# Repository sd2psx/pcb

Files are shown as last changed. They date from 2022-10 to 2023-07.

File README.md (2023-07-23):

# sd2psx: PCB

<table>
<tr>
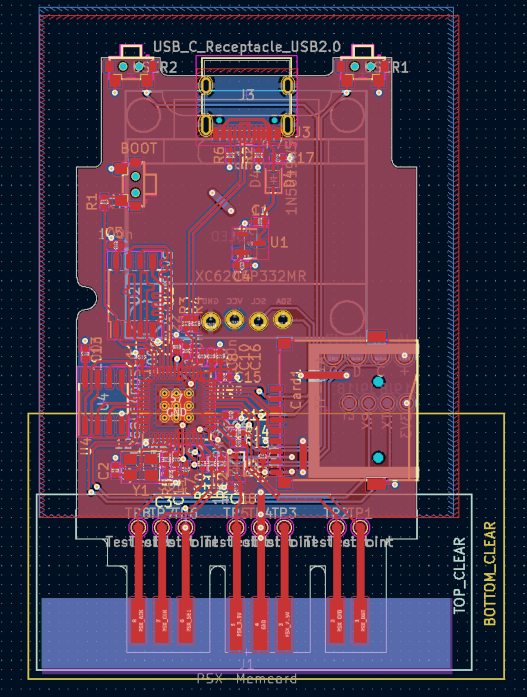
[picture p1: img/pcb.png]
    <td></td>
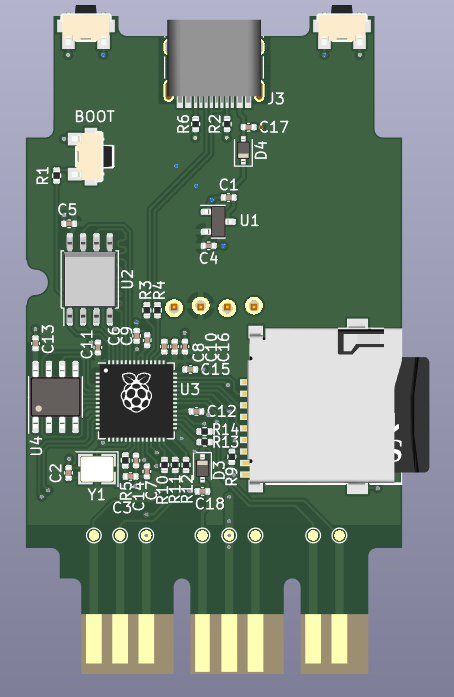
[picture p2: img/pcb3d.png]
    <td></td>
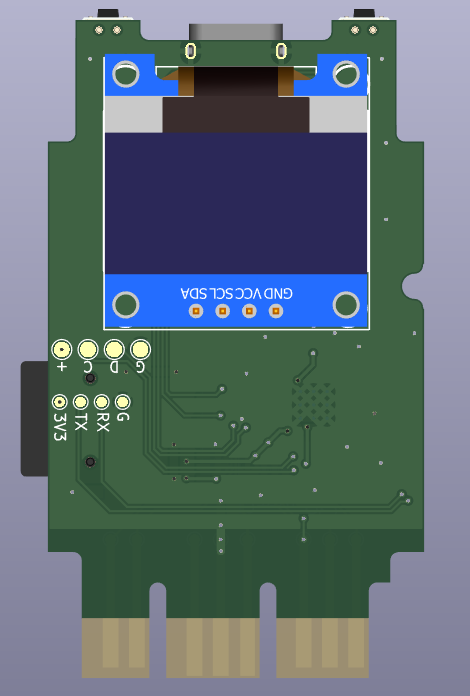
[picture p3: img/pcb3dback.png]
    <td></td>
</tr>
</table>

## Production notes

The PCB must be produced in 0.8mm thickness. Production files are provided under the "Releases" tab. These do not include the through-hole OLED module.

## PSRAM notes (LY68L6400SLIT)

As of June 2023, the LY68L6400SLIT is no longer available from JLCPCB. I've also seen multiple reports of people receiving a **fake chip** when purchasing one from aliexpress. The following chips are a drop-in replacement for the PSRAM:

* IPUS IPS6404LSQ
* ESP PSRAM64H
* AP 6404L-3SQR - Available from [Mouser](https://www.mouser.com/ProductDetail/AP-Memory/APS6404L-3SQR-SN?qs=IS%252B4QmGtzzqsn3S5xo%2FEEg%3D%3D)
* Lyontek LY68L6400S

I recommend switching to the AP 6404L-3SQR module; it can be assembled by JLCPCB by fist ordering it into your [personal parts library](https://jlcpcb.com/user-center/smtPrivateLibrary/?index=1).

## OLED module notes

The case requires a slim OLED module. The more common full-sized module will not fit into the case:

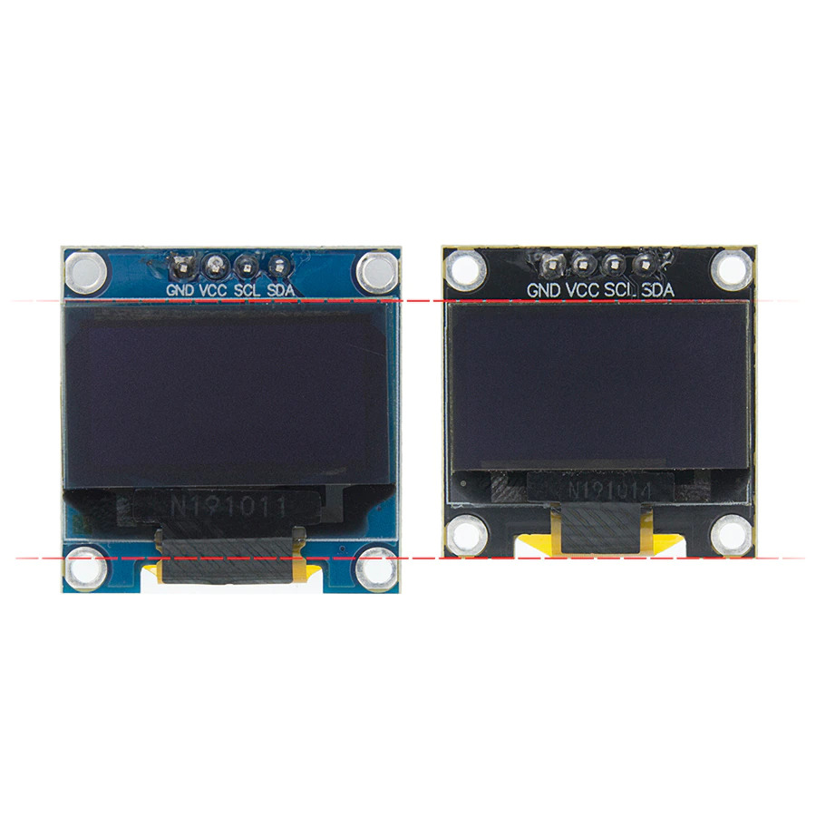
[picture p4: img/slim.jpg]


Examples of compatible modules:
- https://detail.tmall.com/item.htm?id=534583545403&skuId=3942158349315
- https://www.aliexpress.com/item/32638662748.html (make sure to select the smaller module marked as "New-White")

Spec sheet of a compatible module:

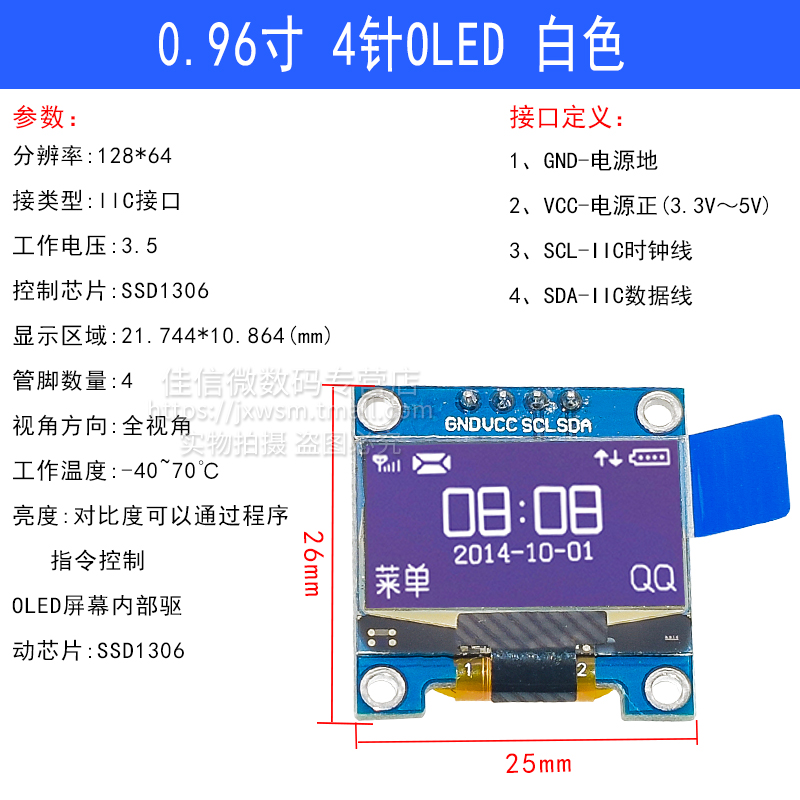
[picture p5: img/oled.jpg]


**Make sure that the pinout goes GND/VCC/SCL/SDA**. There are modules that swap GND/VCC around, these won't work.

## Assembly tips

When attaching the module to the PCB, remove protective OLED screen film (to prevent misalignment), then drop the module into the case so that the screen ends up flush against the case wall. Solder it on in that setup, then clip the pins:

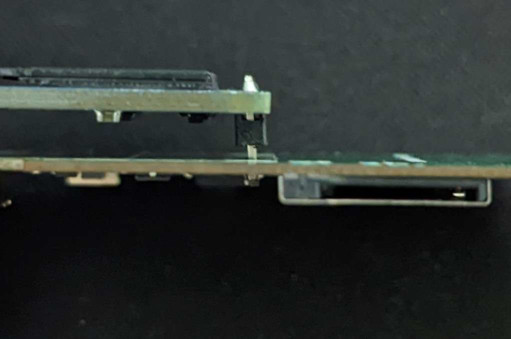
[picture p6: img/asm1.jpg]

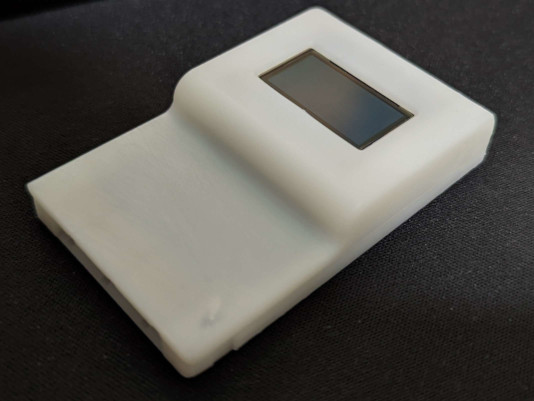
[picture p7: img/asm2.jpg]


There may be extra space between the pin header and the PCB, depending on your 3d print tolerances, but when fully assembled it should look nice and flush.

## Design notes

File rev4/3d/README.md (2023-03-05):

Files in this directory are **not** covered under the CERN-OHL-P license.

# HRO-TYPE-C-31-M-12.step

https://github.com/ai03-2725/Type-C.pretty/blob/master/HRO%20%20TYPE-C-31-M-12.step

# oled_128x64_25x66mm.stp

https://grabcad.com/library/0-96-inch-oled-lcd-module-4-pin-128x64-1

# RP2040_QFN_PACKAGE.STEP

https://grabcad.com/library/rp2040-1

# SOIC-8-208MIL.stp

https://grabcad.com/library/soic-8-208mils-1

# SWITCH_xiaobeibei.STEP

https://grabcad.com/library/tactile-switch-button-push-ts-018-2x4x3-5mm-1

# TF-01A.step

https://grabcad.com/library/tf-01a-1

# switch-3p.step

https://grabcad.com/library/tactile-switch-3p-4-5-x-4-5-x-9-mm-1

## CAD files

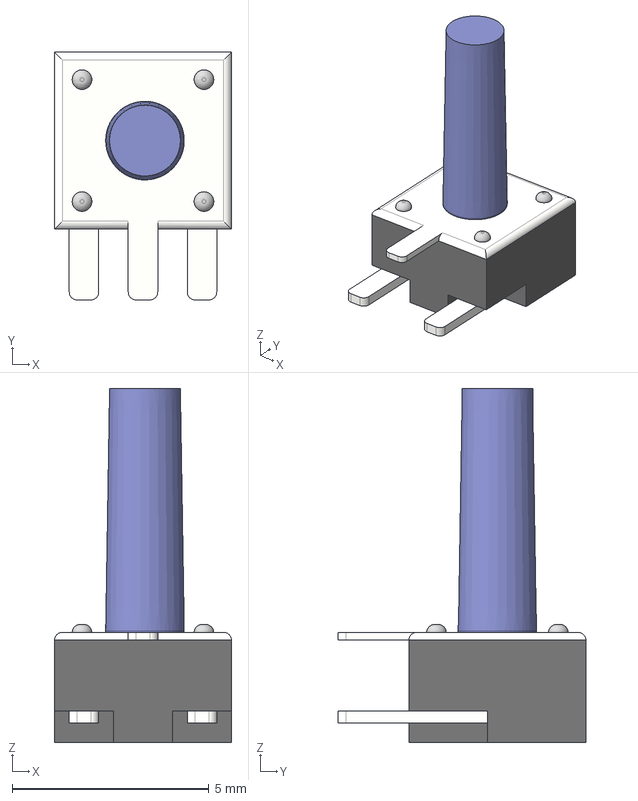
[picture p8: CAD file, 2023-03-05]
rev4/3d/switch-3p.step
4.50 x 6.30 x 9.00 mm

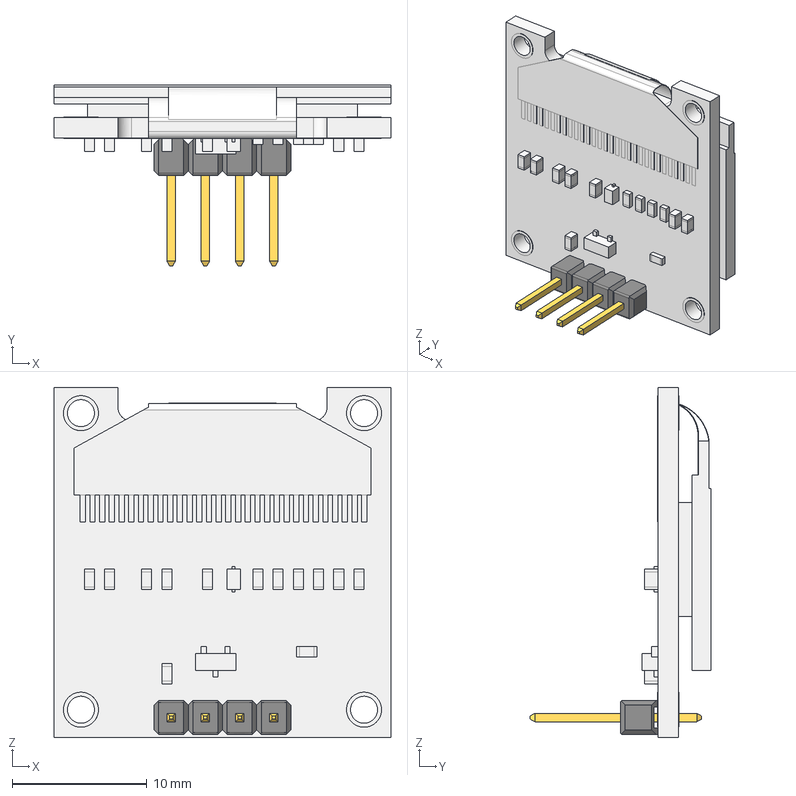
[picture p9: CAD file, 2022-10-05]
rev4/3d/oled_128x64_25x66mm.stp
25.0 x 13.4 x 26.0 mm
OSSD-128x64
brep_1
brep_2
brep_3
brep_4

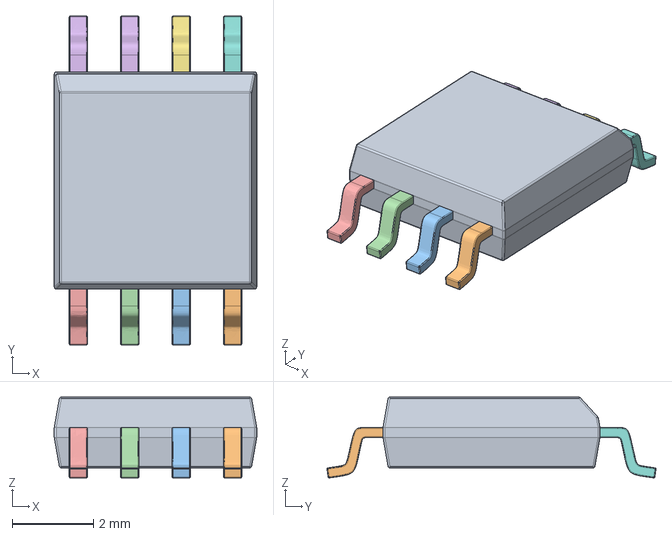
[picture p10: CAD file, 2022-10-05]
rev4/3d/SOIC-8-208MIL.stp
5.00 x 8.12 x 2.00 mm

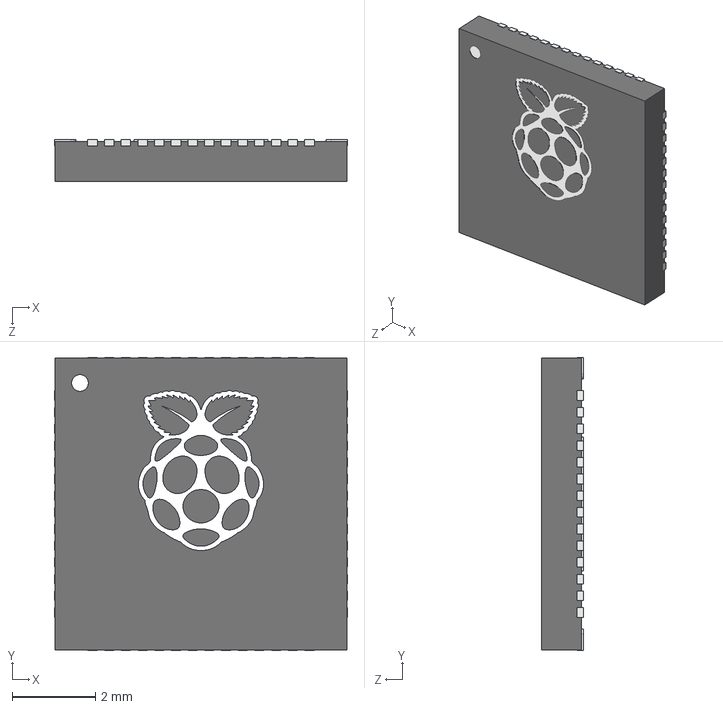
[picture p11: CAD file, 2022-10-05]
rev4/3d/RP2040_QFN_PACKAGE.STEP
7.02 x 7.02 x 1.00 mm

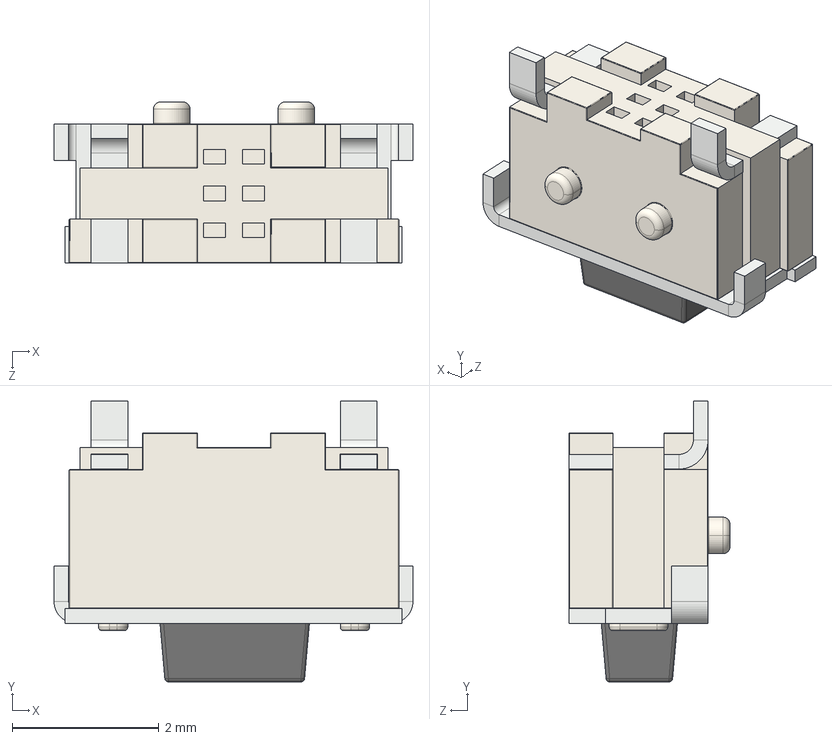
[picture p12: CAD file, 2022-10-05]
rev4/3d/SWITCH_xiaobeibei.STEP
4.90 x 3.83 x 2.20 mm
xiaobeibei_body
xiaobeibei_cap
xiaobeibei_plate
xiaobeibei_pin x 2

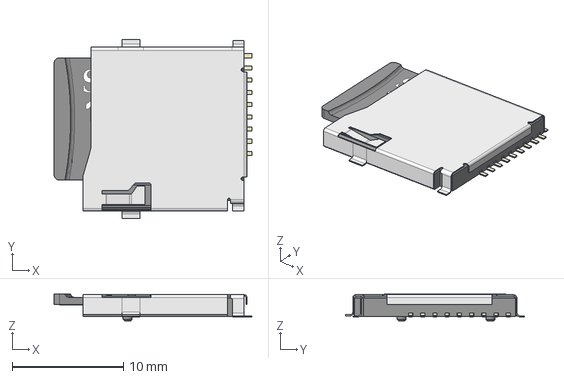
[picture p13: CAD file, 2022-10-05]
rev4/3d/TF-01A.step
17.8 x 16.1 x 2.40 mm

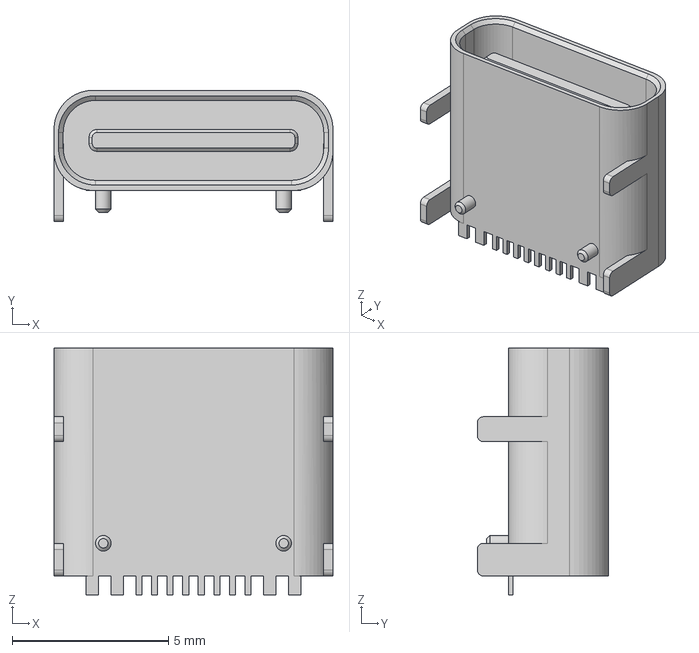
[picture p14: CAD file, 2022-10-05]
rev4/3d/HRO-TYPE-C-31-M-12.step
8.94 x 4.21 x 7.90 mm

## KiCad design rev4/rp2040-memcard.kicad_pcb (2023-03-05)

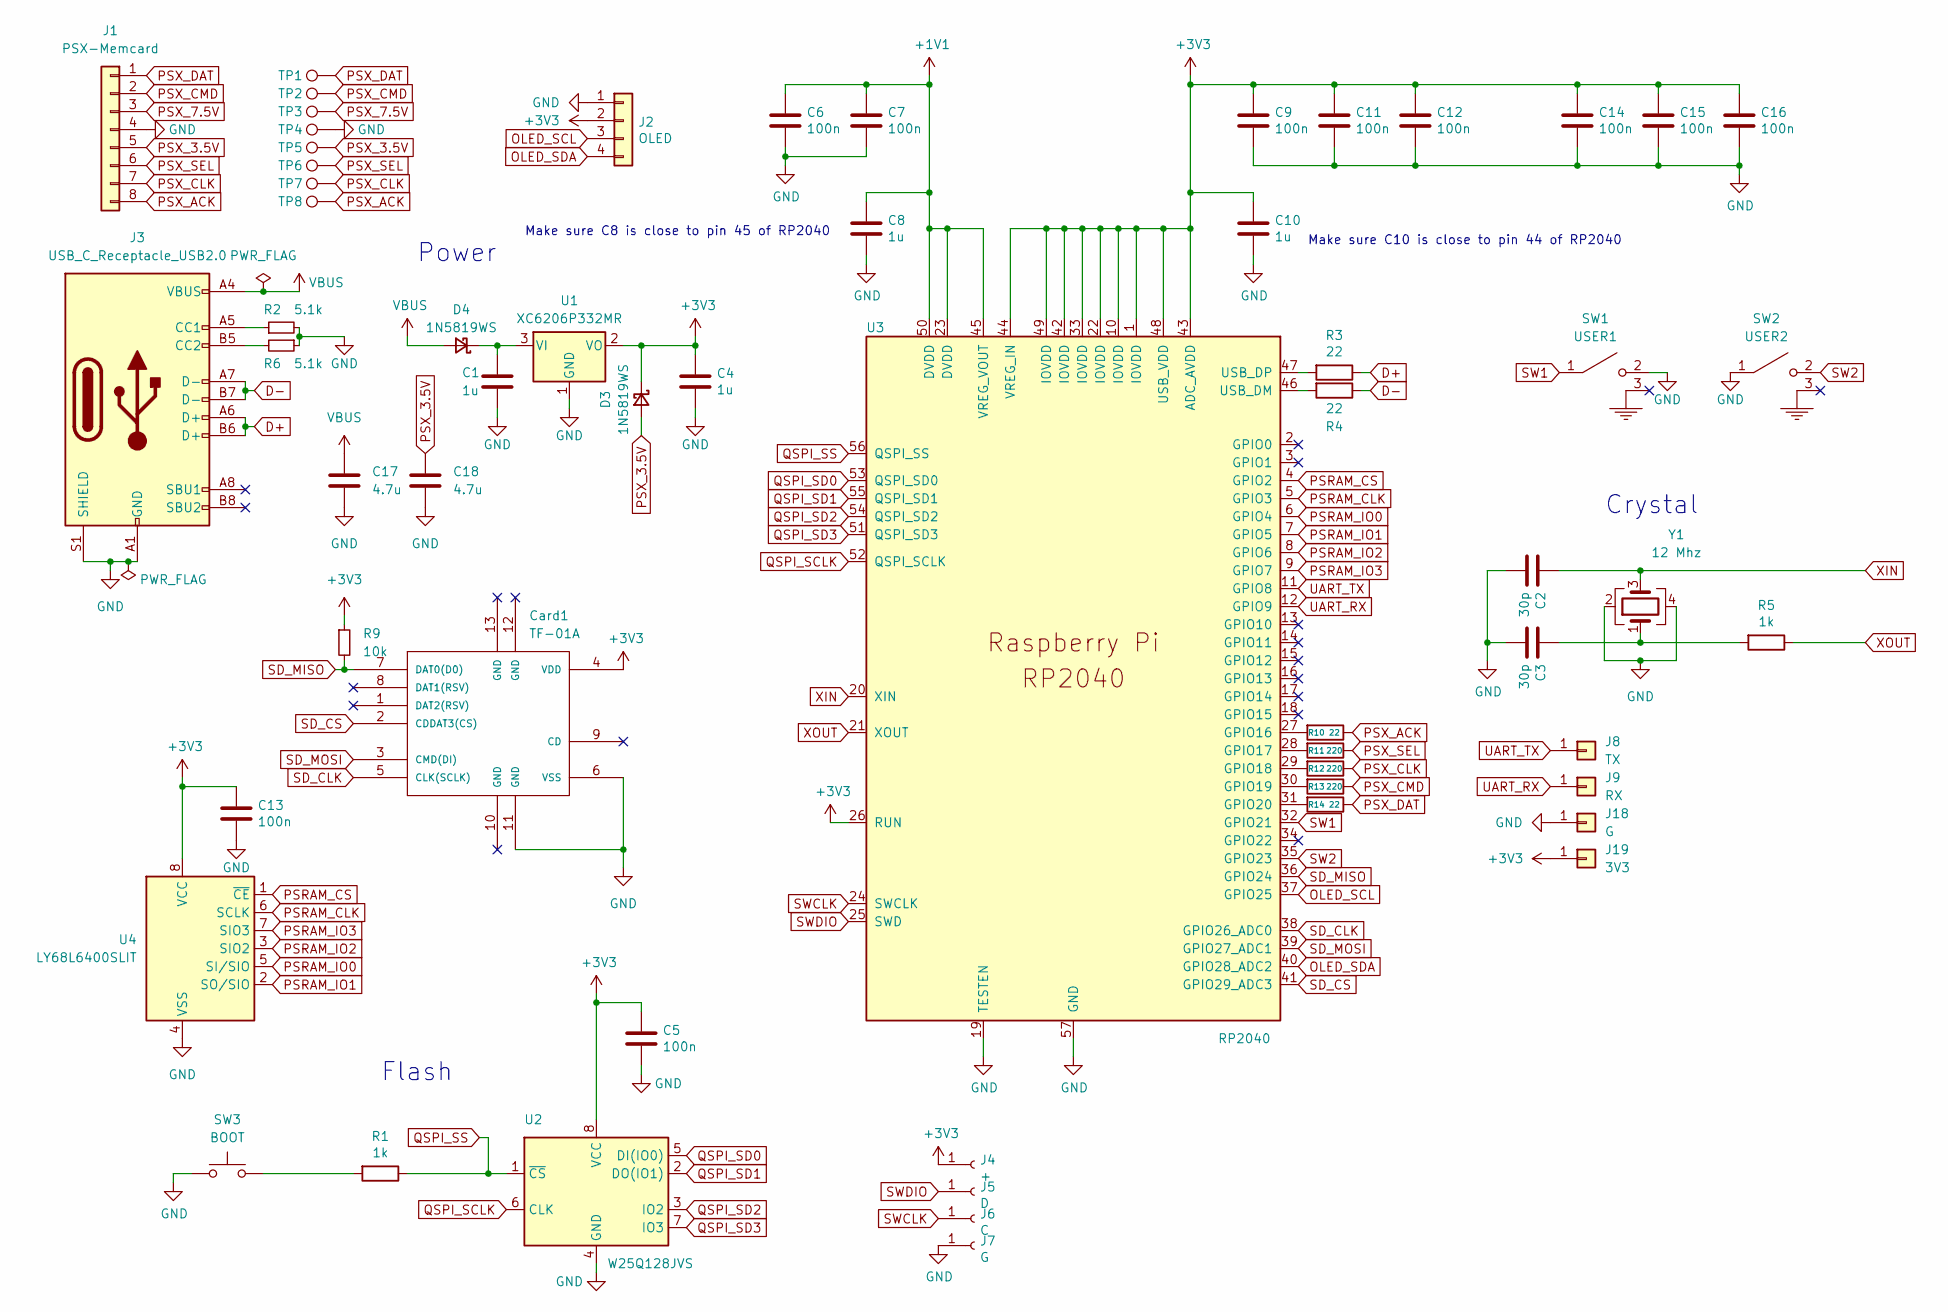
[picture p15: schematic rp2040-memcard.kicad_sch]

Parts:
C1, C4, C8, C10: 1u; C_0402_1005Metric; LCSC C52923
C2, C3: 30p; C_0402_1005Metric; LCSC C1570
C5, C6, C7, C9, C11, C12, C13, C14, C15, C16: 100n; C_0402_1005Metric; LCSC C1525
C17, C18: 4.7u; C_0402_1005Metric; LCSC C23733
Card1: TF-01A; TF-SMD_TF-01A; LCSC C91145
D3, D4: 1N5819WS; D_SOD-323; LCSC C191023
J1: PSX-Memcard; PlayStation_Memory_Card
J2: OLED; SSD1306
J3: USB_C_Receptacle_USB2.0; USB_C_Receptacle_HRO_TYPE-C-31-M-12; LCSC C2765186
J4: +; TestPoint_Pad_D1.5mm
J5: D; TestPoint_Pad_D1.5mm
J6: C; TestPoint_Pad_D1.5mm
J7: G; TestPoint_Pad_D1.5mm
J8: TX; TestPoint_Pad_D1.0mm
J9: RX; TestPoint_Pad_D1.0mm
J18: G; TestPoint_Pad_D1.0mm
J19: 3V3; TestPoint_Pad_D1.0mm
R1, R5: 1k; R_0402_1005Metric; LCSC C11702
R2, R6: 5.1k; R_0402_1005Metric; LCSC C25905
R3, R4, R10, R14: 22; R_0402_1005Metric; LCSC C25092
R9: 10k; R_0402_1005Metric; LCSC C25744
R11, R12, R13: 220; R_0402_1005Metric; LCSC C25091
SW1: USER1; SW-TH_TSC017A10026A
SW2: USER2; SW-TH_TSC017A10026A
SW3: BOOT; PinHeader_1x02_P2.00mm_Vertical; LCSC C393942
TP1, TP2, TP3, TP4, TP5, TP6, TP7, TP8: TestPoint; TestPoint_Pad_D1.0mm
U1: XC6206P332MR; SOT-23; LCSC C5446
U2: W25Q128JVS; SOIC-8_5.23x5.23mm_P1.27mm; LCSC C97521
U3: RP2040; RP2040-QFN-56; LCSC C2040
U4: LY68L6400SLIT; SOIC-8_3.9x4.9mm_P1.27mm; LCSC C261881
Y1: 12 Mhz; Crystal_SMD_3225-4Pin_3.2x2.5mm; LCSC C9002

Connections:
+1V1: C6.1, C7.1, C8.1, U3.23 (DVDD), U3.45 (VREG_VOUT), U3.50 (DVDD)
+3V3: C4.1, C5.1, C9.1, C10.1, C11.1, C12.1, C13.1, C14.1, C15.1, C16.1, Card1.4 (VDD), D3.1 (K), J2.2, J4.1, J19.1, R9.1, U1.2 (VO), U2.8 (VCC), U3.1 (IOVDD), U3.10 (IOVDD), U3.22 (IOVDD), U3.26 (RUN), U3.33 (IOVDD), U3.42 (IOVDD), U3.43 (ADC_AVDD), U3.44 (VREG_IN), U3.48 (USB_VDD), U3.49 (IOVDD), U4.8 (VCC)
D+: J3.A6 (D+), J3.B6 (D+), R3.1
D-: J3.A7 (D-), J3.B7 (D-), R4.1
GND: C1.2, C2.2, C3.2, C4.2, C5.2, C6.2, C7.2, C8.2, C9.2, C10.2, C11.2, C12.2, C13.2, C14.2, C15.2, C16.2, C17.1, C18.1, Card1.6 (VSS), Card1.11 (GND), J1.4, J2.1, J3.A1 (GND), J3.A12 (GND), J3.B1 (GND), J3.B12 (GND), J3.S1 (SHIELD), J7.1, J18.1, R2.2, R6.1, SW1.2, SW2.1, SW3.1, TP4.1, U1.1 (GND), U2.4 (GND), U3.19 (TESTEN), U3.57 (GND), U4.4 (VSS), Y1.2, Y1.4
unnamed: C1.1, D4.1 (K), U1.3 (VI)
unnamed: C3.1, R5.2, Y1.1
unnamed: J3.A5 (CC1), R2.1
unnamed: J3.B5 (CC2), R6.2
unnamed: R1.2, SW3.2
unnamed: R3.2, U3.47 (USB_DP)
unnamed: R4.2, U3.46 (USB_DM)
unnamed: R10.2, U3.27 (GPIO16)
unnamed: R11.2, U3.28 (GPIO17)
unnamed: R12.2, U3.29 (GPIO18)
unnamed: R13.2, U3.30 (GPIO19)
unnamed: R14.2, U3.31 (GPIO20)
OLED_SCL: J2.3, U3.37 (GPIO25)
OLED_SDA: J2.4, U3.40 (GPIO28_ADC2)
PSRAM_CLK: U3.5 (GPIO3), U4.6 (SCLK)
PSRAM_CS: U3.4 (GPIO2), U4.1 (~CE)
PSRAM_IO0: U3.6 (GPIO4), U4.5 (SI/SIO)
PSRAM_IO1: U3.7 (GPIO5), U4.2 (SO/SIO)
PSRAM_IO2: U3.8 (GPIO6), U4.3 (SIO2)
PSRAM_IO3: U3.9 (GPIO7), U4.7 (SIO3)
PSX_3.5V: C18.2, D3.2 (A), J1.5, TP5.1
PSX_7.5V: J1.3, TP3.1
PSX_ACK: J1.8, R10.1, TP8.1
PSX_CLK: J1.7, R12.1, TP7.1
PSX_CMD: J1.2, R13.1, TP2.1
PSX_DAT: J1.1, R14.1, TP1.1
PSX_SEL: J1.6, R11.1, TP6.1
QSPI_SCLK: U2.6 (CLK), U3.52 (QSPI_SCLK)
QSPI_SD0: U2.5 (DI(IO0)), U3.53 (QSPI_SD0)
QSPI_SD1: U2.2 (DO(IO1)), U3.55 (QSPI_SD1)
QSPI_SD2: U2.3 (IO2), U3.54 (QSPI_SD2)
QSPI_SD3: U2.7 (IO3), U3.51 (QSPI_SD3)
QSPI_SS: R1.1, U2.1 (~CS), U3.56 (QSPI_SS)
SD_CLK: Card1.5 (CLK(SCLK)), U3.38 (GPIO26_ADC0)
SD_CS: Card1.2 (CDDAT3(CS)), U3.41 (GPIO29_ADC3)
SD_MISO: Card1.7 (DAT0(D0)), R9.2, U3.36 (GPIO24)
SD_MOSI: Card1.3 (CMD(DI)), U3.39 (GPIO27_ADC1)
SW1: SW1.1, U3.32 (GPIO21)
SW2: SW2.2, U3.35 (GPIO23)
SWCLK: J6.1, U3.24 (SWCLK)
SWDIO: J5.1, U3.25 (SWD)
UART_RX: J9.1, U3.12 (GPIO9)
UART_TX: J8.1, U3.11 (GPIO8)
VBUS: C17.2, D4.2 (A), J3.A4 (VBUS), J3.A9 (VBUS), J3.B4 (VBUS), J3.B9 (VBUS)
XIN: C2.1, U3.20 (XIN), Y1.3
XOUT: R5.1, U3.21 (XOUT)

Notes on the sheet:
Make sure C10 is close to pin 44 of RP2040
Make sure C8 is close to pin 45 of RP2040
Crystal
Power
Flash

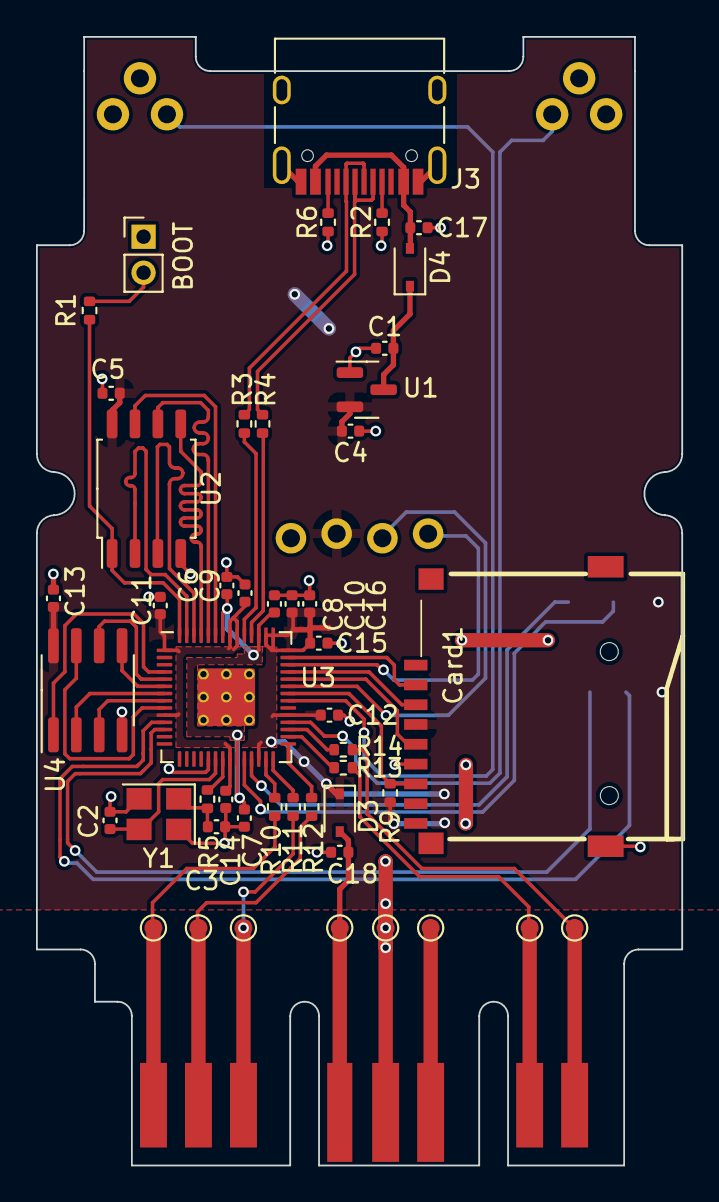
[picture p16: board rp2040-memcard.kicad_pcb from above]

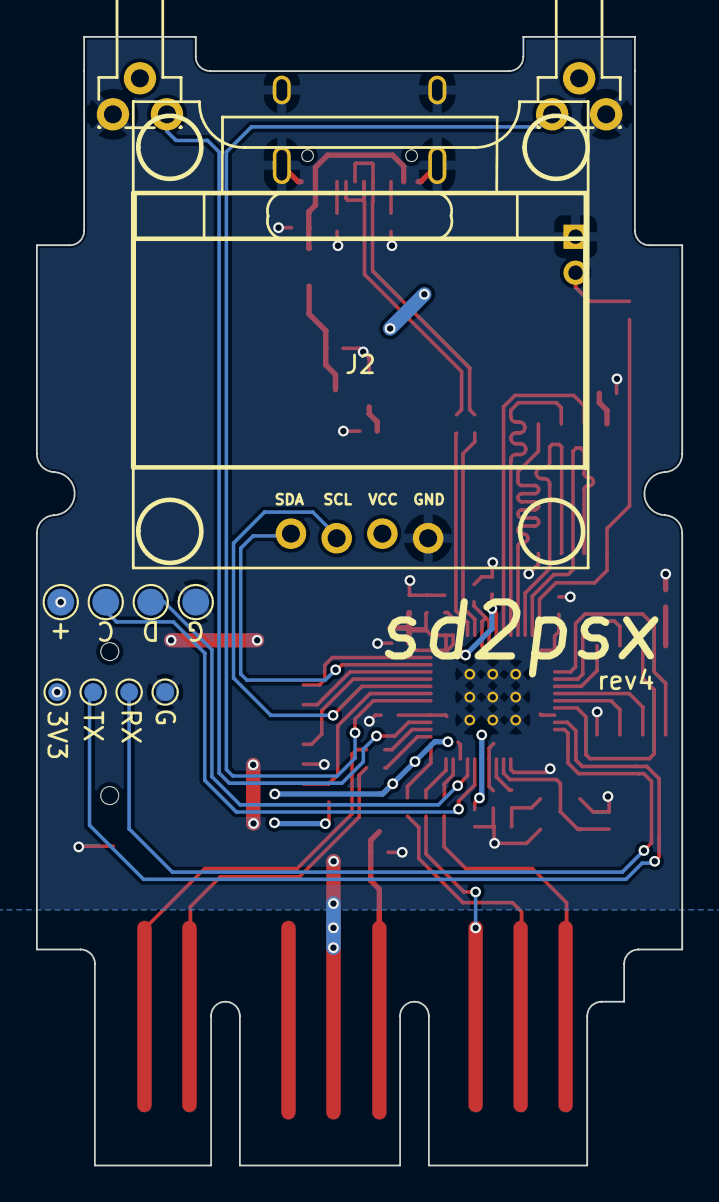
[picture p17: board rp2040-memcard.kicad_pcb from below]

Board: 2 copper layers, 35.9 x 62.7 mm, 60 parts (11 on the bottom side), 51 nets.

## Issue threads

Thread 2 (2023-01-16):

ps1 can working but ps2 mode can't working

hpx1984, 2023-01-16:
Dear Sir

this really a great project for PSx
i very like it

i build 2sets and can working on PS1
i also saw there has PS2 mode and then it change it to ps2 mode and plug it to PS2 , OLED no display and no working
and then i plug it to PS1 still no display and no working

any possible for fix it ？or it is damage
please help ,many thanks sir

xyzz, 2023-01-16:
First update to the latest firmware from https://github.com/sd2psx/firmware/releases/tag/latest
After that, it should show a fatal error message on the OLED screen if there's any error. If PS1 mode works but PS2 mode doesn't it may be an error with the PSRAM chip:
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
If it's still not showing anything on the screen after firmware update, to get debug output you can:
1) solder to UART (TX/RX/G pins) on the back, then check output with 3000000 baud mode
2) after this line <https://github.com/sd2psx/firmware/blob/076baf6d56afa501adc0e12e0e616a930d5d69dd/src/main.c#L64> add:
```
    stdio_usb_init();
    sleep_ms(5000);
```
then it will provide a USB COM port for debugging messages, you can plug it into a PC and look for any error messages.

xyzz, 2023-01-16:
Also after you change to PS2 mode, don't plug it into PS1 because it may damage the chip or the console.

hpx1984, 2023-01-16:
Dear Sir xyzz

many thanks your quickly replied
yes , i saw the information you remind the user after confirmed change to PS2 mode

actually i had not mount the U4 on board so that is the problem way could not working after change to PS2  on my side，right？
i will try to buy some U4 for complete the build , now just used it on PS1

hpx1984, 2023-01-16:
Dear Sir xyzz

many thanks your quickly replied
yes , i saw the information you remind the user after confirmed change to PS2 mode

actually i had not mount the U4 on board so that is the problem way could not working after change to PS2  on my side，right？
i will try to buy some U4 for complete the build , now just used it on PS1

xyzz, 2023-01-16:
yes, it is required for PS2 mode to work

Closed 2023-01-16.

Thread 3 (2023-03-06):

Black screen on PS1 and Ps2 mode

Tungraider, 2023-03-06:
Dear Sir

I really liked the project but I'm not having any luck

the card works connected to the usb but on the consoles it does not show a sign of life, it always appears a black screen on the oled and the console does not recognize it either

Thanks

xyzz, 2023-03-06:
Please install the usb debug firmware from https://github.com/sd2psx/firmware/releases/download/latest/sd2psx_usb_debug.uf2 and then provide a log from tera term - https://ttssh2.osdn.jp/index.html.en

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

Tungraider, 2023-03-06:
ok, i got this log
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

xyzz, 2023-03-06:
There is no error here, if it's still not working maybe it has bad contact with the memory card slot? Check all of the termination resistors on the pcb look good, also check if there are any shorts on the pcb. Did you order this from a store or make one yourself?

Tungraider, 2023-03-06:
Hi sir
Again I apologize, after checking all the components I discovered a poorly soldered diode by the company that I ordered the assembled pcb and after soldering the same the sd2psx worked perfectly, thanks for the feeback and congratulations for the project

Closed 2023-03-06.

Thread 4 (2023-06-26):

SW1 and Sw2 are on the wrong side of the board

Gardosen, 2023-06-26:
Hello,

to redesign a case from someone for the rev4 boards, i tried to export your kicad project to blender and over to fusion.
while doing this i noticed this.

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

i could be mistaken, but it should look like this, should it?
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

Kind regards
Gardosen

xyzz, 2023-06-26:
The first image is the correct position; it requires to cut the OLED display module a little:

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

If put on the other side, the buttons clip through the case like so

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

It's not bad enough to cause compatibility issues with other hardware plugged in, like a bluetooth controller adapter, but you'd either have to add a bump or a hole at the bottom and I figured cutting a bit of oled pcb is a better compromise.

xyzz, 2023-06-26:
Also check out the existing rev4 case design in https://github.com/sd2psx/case/tree/main/rev4

Gardosen, 2023-06-27:
Hey,

thanks for letting me know, i'm sorry for the disturbance, thanks for the detailed explenation where my mistake is, i indeed forgot to put the bottom plate on the design to check the conflict with the buttons.

kind regards
Marco

Closed 2023-06-27.

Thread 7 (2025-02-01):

Tactile switch in BOM

DfknG, 2025-02-01:
Is the switch model in the v4 BOM correct? It references a 10mm button stalk which seems too large?

https://jlcpcb.com/partdetail/BZCN-**TSC017A10026A**/C2888536
https://www.lcsc.com/product-detail/Tactile-Switches_BZCN-TSC017A10026A_C2888536.html?s_z=n_TSC017A10026A

xyzz, 2025-02-02:
this is a sample model, the correct size is 7mm measured from the bottom

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

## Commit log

2023-02-26 move current pcb to rev3
    [HRO-TYPE-C-31-M-12.step, RP2040_QFN_PACKAGE.STEP, SOIC-8-208MIL.stp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]
2023-02-26 init rev4 as copy of rev3
    [HRO-TYPE-C-31-M-12.step, RP2040_QFN_PACKAGE.STEP, SOIC-8-208MIL.stp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]
2023-03-05 finalize rev4
    [rp2040-memcard.kicad_pcb, rp2040-memcard.kicad_sch, switch-3p.step]
2023-03-05 exclude drc errors for overlapping oled and switch
2023-03-06 remove boot button
    [rp2040-memcard.kicad_sch]
